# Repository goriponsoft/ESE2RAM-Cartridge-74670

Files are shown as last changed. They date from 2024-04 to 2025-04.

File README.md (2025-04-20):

# 似非²RAMカートリッジ(1Mbyte版)
[English README is here](README-en.md)

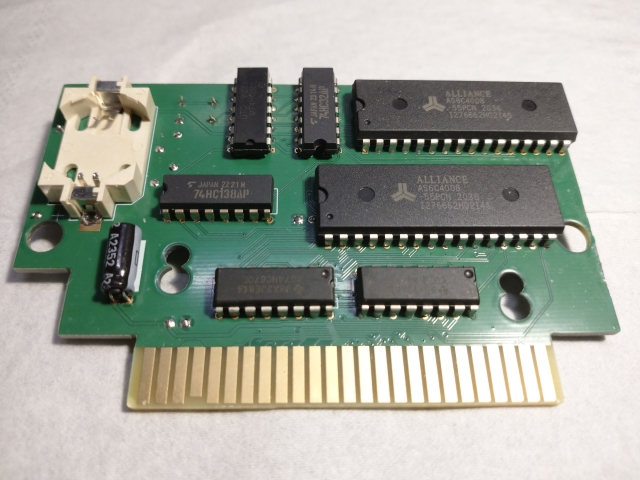
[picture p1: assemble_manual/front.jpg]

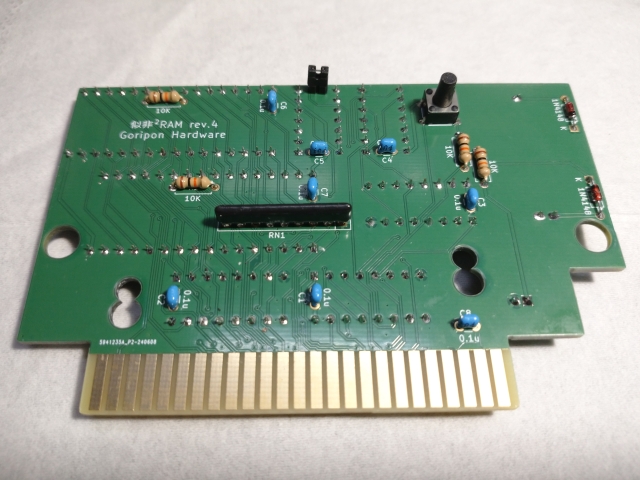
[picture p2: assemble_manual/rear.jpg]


これは、汎用ロジックICによりメガROMコントローラと同等の動作を実現し、それを利用して似非RAMを構築したMSX用カートリッジ(命名:似非・似非RAMまたは似非²RAM)です。
ごりぽんハードウェア(同人サークル・ごりぽんソフトウェアのハードウェア部門)により作成されました。

KiCAD7用の回路図データ・基板データ・ガーバーデータを、クリエイティブ・コモンズライセンス(CC-BY-NC)で公開しています。
[MGINST215.zip](https://github.com/goriponsoft/ESE2RAM-Cartridge-74670/blob/main/MGINST215.zip)および[KSAVER105.zip](https://github.com/goriponsoft/ESE2RAM-Cartridge-74670/blob/main/KSAVER105.zip)はCCライセンスの対象ではなく、元のライセンスと条件が適用されます。

X(旧Twitter): @goriponsoft

## 似非RAMディスク(似非RAM)とは？

[同人サークル・似非職人工房](http://www.hat.hi-ho.ne.jp/tujikawa/ese/)のつじかわ氏が考案した、ストレージなどとして使えるMSX用の汎用バックアップRAMカートリッジです。

通常は、ゲームのメガROMカートリッジを改造し、ROMをRAMに置き換えることで制作します。MGINSTコマンドによりDOSカーネルをインストールしてSSDのようなストレージとして利用したり(似非RAMディスク)、メガROMのイメージを読み込ませて動作させたりすることができます。

もともとストレージとしての使用を前提に考案されたため、カートリッジ自体も「似非RAMディスク」と呼ぶほうが一般的です。

なお、所有していないゲームのイメージを読み込ませて利用することは違法行為です。通常は似非RAMディスクの他、似非RAMに改造することで使用できなくなる改造元ゲームカートリッジのイメージ(改造前にファイルに書き出しておく必要あり)、フリーウェア、自作ROMゲーム、などを動作させるのに使用します。

似非RAMディスクについての詳細は、[似非職人工房の似非RAMディスクのページ](http://www.hat.hi-ho.ne.jp/tujikawa/ese/eseram.html)を参照してください。

## 似非²RAM(似非・似非RAM)とは？

近年MSXゲームの入手自体が難しくなり、貴重になってしまったメガROMカートリッジを潰して似非RAMにするのはかなり躊躇われる状況でした。そこで、普通に入手できる汎用ロジックICを使い、メガROMコントローラーと同等の回路を実現し、それを利用して似非RAMとして組み上げたのがこのカートリッジです。

似非RAMでありながら、メガROMコントローラを使用していない「似て非なる似非RAM」ということで「似非・似非RAM」、転じて「似非の2乗」で「似非²RAM」と命名しました。上付き文字の使用に問題がある場合は「似非2RAM」や「似非似非RAM」でも構いません。英語表記は「ESE-ESE-RAM」または「ESE2-RAM」です。

## 部品表
注意: 基板Rev.6以降U3～U5が74HCシリーズから74AHCシリーズに変更されています
|部品番号|内容|数量|
|:--|:--|--:|
|BT1|CR2032電池ホルダ "CH29-2032LF"/"CH28-2032LF(TR)"/"CH004-2032LF"/"CH004-2032LF"のいずれか|1|
|C1-C8|セラミックコンデンサ 0.1μF・50V・2.5mmピッチ|8|
|C9|電解コンデンサ 47μF・16V|1|
|D1-D2|ダイオード "1N4148"|2|
|IC1-IC2|4Mbit SRAM(628512タイプ・512K×8) DIP-32 "AS6C4008"など|2|
|R1-R4|抵抗 1/4W・10KΩ|4|
|RN1|集合抵抗 8素子・10KΩ SIP-9|1|
|S1|6×6mm タクトスイッチ "TVDP01-095BB1"|1|
|U1-U2|汎用ロジックIC "74HC670"|2|
|U3|汎用ロジックIC "74AHC138"|1|
|U4|汎用ロジックIC "74AHC00"|1|
|U5|汎用ロジックIC "74AHC32"|1|
|-|CR2032電池|1|

## 組み立て方
基板の実装面積の関係で、抵抗、コンデンサ、ダイオードなどの部品が裏面(ハンダ面)に配置されているため、組み立てには注意が必要です。

[詳細な組み立てマニュアル(日本語版)はこちら](assemble_manual/main.md)

1. 基板を裏返して(コネクタの傍に「Front」と書かれている側が表面です)、シルク印刷を参考に、ダイオード、抵抗、セラミックコンデンサ、集合抵抗、の順で部品を配置して表側(部品面)からハンダ付けします。ハンダを盛りすぎると、ICと基板の間に隙間ができるので、ハンダの量は控えめにしてハンダ付けしてください。
2. ハンダ付けしたら、表面に余ったリードを切断します。リードが余分に残っていると、やはりICと基板の間に隙間ができるので、こちらもできるだけ短くなるように切断してください。
3. 基板を表に戻し、IC、電解コンデンサ、セラミックコンデンサを配置し、通常通り裏面(ハンダ面)からハンダ付けしていきます。電解コンデンサはシルク印刷の方向に横倒しにして実装してください(縦に実装するとカートリッジシェルに収まりません)。ICやコンデンサのリードの処理は通常通りで構いません。
4. タクトスイッチと電池ホルダをハンダ付けします。標準では、タクトスイッチは裏面、電池ホルダは表面に配置しますが、逆の面に配置することもできますので、お好みで配置してください。
5. ショートや部品の付け間違いがないことを念入りに確認したうえで、MSX実機に挿して動作を確認します。似非RAMディスクとして使わない場合でも、動作確認にはMGINSTを使うのが簡単です。

## 準備 (似非RAMディスクとして使う場合)
1. 似非インストーラー(MGINST.COM)とカーネルセーバー(KSAVER.COM)を入手します([似非職人工房・非公認出張所(似非なページ)](http://www.big.or.jp/~saibara/msx/ese/index-j.html)よりLHA形式のアーカイブをダウンロードすることができます。また、ZIP形式にアーカイブしなおした[MGINST215.zip](https://github.com/goriponsoft/ESE2RAM-Cartridge-74670/blob/main/MGINST215.zip)と[KSAVER105.zip](https://github.com/goriponsoft/ESE2RAM-Cartridge-74670/blob/main/KSAVER105.zip)も、こちらで用意してあります。)
2. 何らかのMSXで起動可能なストレージ(通常はフロッピーディスク)に上記ツールを展開したものと、MSX-DOSのシステムファイル(MSXDOS.SYS/COMMAND.COM)をコピーします。MSX-DOS2カーネル利用の場合は、加えてMSX-DOS2のシステムファイル(MSXDOS2.SYS/COMMAND2.COM)をコピーしておくと、似非RAMインストール時に自動的にコピーされ、MSX-DOS2で起動することができるようになります。
3. MSX実機に似非²RAMカートリッジを挿し、タクトスイッチを押したまま電源を入れ、手順2で作成したストレージからMSX-DOS(またはMSX-DOS2)を起動します。
4. KSAVER.COMを使用し、MSX本体からMSX-DOSまたはMSX-DOS2のカーネルをファイルに保存します(詳細はKSAVERの付属ドキュメントを参照)。
5. MGINST.COMを使用し、手順4で保存したカーネルのファイルを指定して似非RAMカーネルをインストールします(詳細はMGINSTの付属ドキュメントを参照)。
6. リセットし似非RAMディスクから起動することを確認します。

手順4で保存したカーネルファイルは不要ですので、削除してしまっても構いません。残しておくと、似非RAMディスクの再インストール時に手順を省略できます。

手順5でエラーが出る場合は、部品のハンダ付け不良の可能性が高いので、基板をチェックしてみてください。

## 使い方 (メガROMソフトウェアを動かす場合)
使用した部品の機能の関係で、当カートリッジでは、セグメント番号の初期値がASCIIマッパーと異なっているため、プログラムによるレジスタの初期化が必須となっています。似非RAMディスクやゲームを含む、ほとんどのメガROMソフトウェアでは適切に初期化が行われているので問題ありませんが、初期化を怠っていたり、セグメント初期値が特定の値であることを期待しているソフトウェアは動作しない場合があります。

当カートリッジの起動直後もしくはリセット直後のバンクは以下のようになっています。

|バンクアドレス|レジスタアドレス|セグメント番号|
|:--|:--|--:|
|4000h-5FFFh|6000h-67FFh|0|
|6000h-7FFFh|6800h-6FFFh|0|
|8000h-9FFFh|7000h-77FFh|0|
|A000h-BFFFh|7800h-7FFFh|0|

この状態からレジスタに値を書き込むと、書き込んだレジスタは書き込んだ値に、書き込まれていないレジスタは不定値に切り替わります。

例えば6000hに0を書き込んだ場合は以下のようになります。

|バンクアドレス|セグメント番号|
|:--|--:|
|4000h-5FFFh|0|
|6000h-7FFFh|不定|
|8000h-9FFFh|不定|
|A000h-BFFFh|不定|

このため、当カートリッジで自作メガROMソフトウェアを動作させる場合は、INITエントリのできるだけ早い段階で、実行中のアドレスを含むバンクのレジスタに0を書き込んで初期化する必要があります。実行中のアドレスを含まないバンクのレジスタに先に書き込んでしまうと、実行中のプログラムが不定のバンクに切り替わり、ほとんどの場合は暴走します。また、書き込まれなかったレジスタの値は不定ですので、必要であれば初期化を行ってください。

通常はセグメント#0に以下のコードを配置し、ROMヘッダのINITエントリより4000h～5FFFhバンクのコードとして呼び出せば、問題なく初期化できます。
```
	xor		a
	ld		(6000h),a
	ld		(6800h),a
	ld		(7000h),a
	ld		(7800h),a
```

## 互換性情報
動作確認済のハードウェア(順不同)について

ご報告いただいたものは順次追加していきます

### 動作不良が確認されている機種と症状

- ビクター HC-90 および HC-95 (MSX2) : RAMから読み出されたデータが壊れるため正常動作しない
- 東芝 HX-E601 (拡張スロット) : 認識されず起動しない

### 正常動作が確認されている機種

- パナソニック FS-A1ST
- ソニー HB-F1XV
- 三菱 ML-G30model1 および ML-G30model2
- ヤマハ YIS503 および CX5F
- ヤマハ YIS604/128 および CX7M/128
- 三洋 WAVY70FD および WAVY70FD2
- 東芝 HX-31
- 三菱 ML-8000
- ゼネラル PCT-50 および PCT-55
- ソニー HB-F500

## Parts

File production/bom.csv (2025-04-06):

Designator | Footprint | Quantity | Value | LCSC Part #
BT1 | BatteryHolder_CH2x-2032LF | 1 | CR2032
C1, C2, C3, C4, C5, C6, C7, C8 | C_Disc_D3.0mm_W1.6mm_P2.50mm | 8 | 0.1u
C9 | CP_Radial_D5.0mm_P2.00mm_Horizontal | 1 | 47u
D1, D2 | D_DO-35_SOD27_P7.62mm_Horizontal | 2 | 1N4148
IC1, IC2 | DIP32_600mil_FineLongPad | 2 | 4M SRAM
R1, R2, R3, R4 | R_Axial_DIN0207_L6.3mm_D2.5mm_P7.62mm_Horizontal | 4 | 10K
RN1 | R_Array_SIP9 | 1 | 10k
S1 | DTS63NV | 1 | DTS-63N-V
U1, U2 | DIP16_300mil_FineLongPad | 2 | 74HC670
U3 | DIP16_300mil_FineLongPad | 1 | 74AHC138
U4 | DIP14_300mil_FineLongPad | 1 | 74AHC00
U5 | DIP14_300mil_FineLongPad | 1 | 74AHC32

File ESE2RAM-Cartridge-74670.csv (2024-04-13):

Source: | Y:\Project\ESE2RAM-Cartridge-74670\ESE2RAM-Cartridge-74670.kicad_sch
Date: | 2024/04/13 19:58:52
Tool: | Eeschema 7.0.8
Generator: | C:\Program Files\KiCad\7.0\bin\scripting\plugins/bom_csv_grouped_by_value_with_fp.py
Component Count: | 25
Ref | Qnty | Value | Cmp name | Footprint | Description | Vendor | DNP
BT1 | 1 | CR2032 | Battery_Cell | ProjectLibrary:BatteryHolder_CH2x-2032LF | Single-cell battery
C1, C2, C3, C4, C5, C6, C7, C8 | 8 | 0.1u | C_Small | Capacitor_THT:C_Disc_D3.0mm_W1.6mm_P2.50mm | Unpolarized capacitor, small symbol
C9 | 1 | 47u | C_Polarized_Small | ProjectLibrary:CP_Radial_D5.0mm_P2.00mm_Horizontal | Polarized capacitor, small symbol
D1, D2 | 2 | 1N4148 | 1N4148 | Diode_THT:D_DO-35_SOD27_P7.62mm_Horizontal | 100V 0.15A standard switching diode, DO-35
IC1, IC2 | 2 | 4M SRAM | AS6C4008-55PIN | ProjectLibrary:DIP32_600mil_FineLongPad | SRAM 4M, 2.7-5.5V, 55ns 512K x 8 Asynch SRAM
R1, R2, R3, R4 | 4 | 10K | R_Small | Resistor_THT:R_Axial_DIN0207_L6.3mm_D2.5mm_P7.62mm_Horizontal | Resistor, small symbol
RN1 | 1 | 10k | R_Network08 | Resistor_THT:R_Array_SIP9 | 8 resistor network, star topology, bussed resistors, small symbol
S1 | 1 | DTS-63N-V | DTS-63N-V | ProjectLibrary:DTS63NV | 6x6 Through Hole & Ground Terminal Type,TS 6MM V H=7.0 160gf BULK
U1, U2 | 2 | 74HC670 | 74LS670 | ProjectLibrary:DIP16_300mil_FineLongPad | 4 x 4 Register Files 3-State Outputs
U3 | 1 | 74HC138 | 74LS138 | ProjectLibrary:DIP16_300mil_FineLongPad | Decoder 3 to 8 active low outputs
U4 | 1 | 74HC00 | 74LS00 | ProjectLibrary:DIP14_300mil_FineLongPad | quad 2-input NAND gate
U5 | 1 | 74HC32 | 74HC32 | ProjectLibrary:DIP14_300mil_FineLongPad | Quad 2-input OR

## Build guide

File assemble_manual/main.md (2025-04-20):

# 似非²RAM組み立てマニュアル

## 0. 組み立てを始める前に

実は本キットには、いくつかの改造ポイントがあるのですが、組み立て手順の関係で、組み立て開始前に改造のための加工をしておかないと、後からでは改造出来なくなってしまうものがあります。
ということで、いきなりですが改造ポイントについての説明です。改造する気が無い方は、読み飛ばしていただいて構いません。

以下、基板のコネクタ部分を手前(下)に見た位置で示します。基板の表裏については、基板右下コネクタ付近に「Front」の白いシルク印刷のある側が「表」側、基板左上に「似非²RAM」のシルク印刷の文字がある側が「裏」側です。

### ① 1024KB/512KB切替ジャンパピン

U5(74HC32)の7ピンと8ピンの間、基板の上端ギリギリのところに、パスコンとは別の横並びのパターンがあります。これがRAM容量切替ジャンパのパターンです。

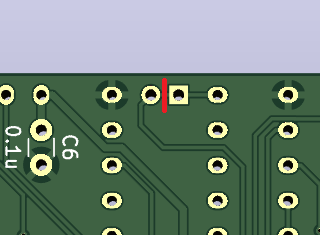
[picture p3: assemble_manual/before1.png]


通常は容量は1MB(1024KB)固定となりますが、基板の裏側の2つのパターンの間の配線(図の赤線)をカットし、同じく裏側からキット付属の2mmピンヘッダ(ジャンパーピン付)を差し込み、表側からハンダ付けすることで、ジャンパピンを挿した状態で1024KB、抜いた状態で512KB、2つの容量に切り替えることができるようになります。512KB時のバンク割当は、0～63(128～191)にIC1のSRAMが見え、64～127(192～255)には何も(バンクのゴーストも)見えない、という状態になります。

こちらの改造ポイントは、表側に74HC32が被せられハンダ付けされてしまうので、ICより先に処理しておかないと、ハンダ付けするパターンがICの下に隠れてしまい、ジャンパピンを取り付けることができなくなってしまいます。また、カットする面にはジャンパピンが配置されているため、パターンカットする前にジャンパピンを付けてしまうと機能しません。

主にメガROMソフトの開発者向けの機能であり、似非RAMディスクとしてのみ使用するのであれば、改造の必要はありません。(なお完成品では改造済みの状態になっています)

### ② RAM減量(512KB化)

①は「1024Kと512Kを切り替えるジャンパ」の改造でしたが、こちらは「容量自体を512KBに減量する」改造です。当然ながらこちらの改造を行った場合、①のジャンパは意味が無くなります。

IC2のSRAMを実装しないことで容量を512KBにすることができます。またIC2に関連するC7とR2も外すことができます。バンク割当は①の512KB時と同様です。

単に部品を省略するだけなので、こちらの改造ポイントは、特に順序などに制限はありません。

### ③ ライトプロテクトスイッチ

通常はSRAMへは常時書き込み許可ですが、U2(74HC670)の6番ピンの裏面側から上方向に伸びている細いパターンをカットし(図の赤線・該当箇所の上部のみ基板の色が少し違います)、この6番ピンとU4(74HC00)の10番ピンの間にスイッチ(キットには付属していません)を付けることで、OFFで書き込み禁止、ONで書き込み許可となる、ライトプロテクトスイッチを付けることができます。

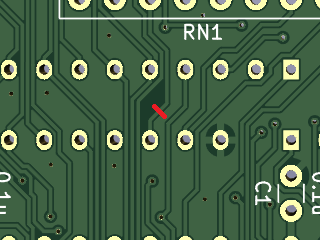
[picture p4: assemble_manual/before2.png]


なお、こちらの改造ポイントは、パターンに重なる部品などは無いため、後からでも加工が可能です。

ただし、このライトプロテクトスイッチは、ソフトウェアからの書き込みに対しては有効ですが、ハードウェアが原因であるSRAM内容の消失に対しては無力です。書き込み禁止にしていたとしても、内容が消失する可能性はありますので、過度の期待はしないでください。

## 1. 裏面からの部品の取り付け(1)

本キットでは基板の面積の都合で、表面と裏面で重なる位置に部品が配置されているため、基板両面から部品の取り付けが必要です。ここでは、裏面(本来はハンダ面)からの取り付けが必要な部品について、取り付け手順を説明します。



### ① 抵抗の取り付け

抵抗のリードを抵抗の本体ギリギリのところで折り曲げ(キットの1/4W抵抗であれば丁度良い幅になるよう設計されています)、R1～R4のパターンに差し込み、テープなどで仮止めしてから、裏返して表面からハンダ付けします。抵抗は全て同じ抵抗値で、向きもありませんので、どれをどの向きに差し込んでも大丈夫です。

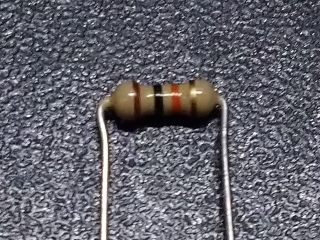
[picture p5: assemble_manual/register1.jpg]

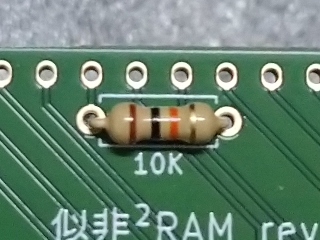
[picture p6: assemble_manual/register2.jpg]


表面の部品と重なる部分については、ハンダを少なめにして、できるだけ盛り上がりのないようにハンダ付けし、余分なリードは基板面ギリギリのところでカットします。

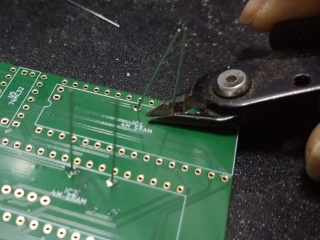
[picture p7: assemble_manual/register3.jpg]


基板に抵抗を取り付けた状態です。

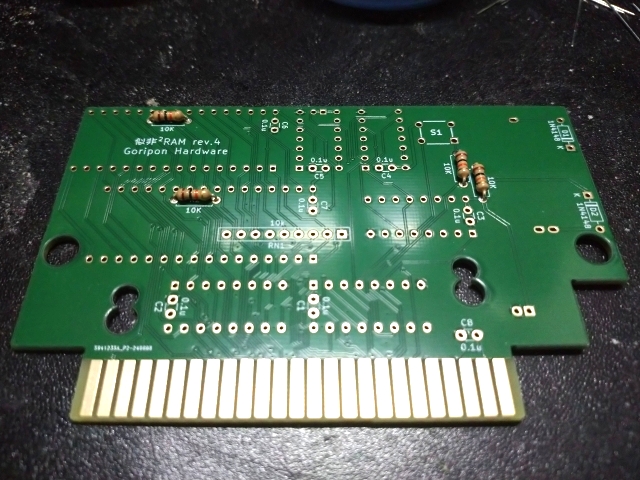
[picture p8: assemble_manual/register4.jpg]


### ② ダイオードの取り付け

ダイオードのリードを折り曲げ(前項目の抵抗と同じくらいの幅になるようにします)、D1～D2のパターンに差し込み、テープなどで仮止めしてから、裏返して表面からハンダ付けします。ダイオードは青いラインの入っている側がK(カソード)ですので、基板上の白いシルク印刷の「K」と合わせて、向きを間違えないように差し込んでください。

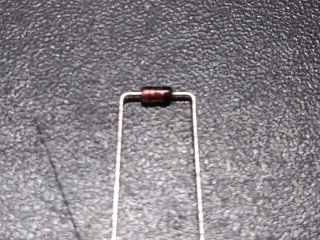
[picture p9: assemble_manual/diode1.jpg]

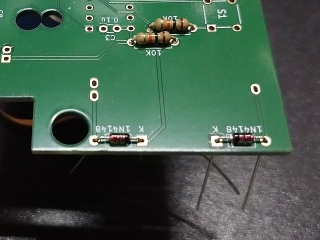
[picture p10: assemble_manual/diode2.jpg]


ダイオードは裏面に重なる部品が無いため、ハンダ付けは通常通りで構いません。ただし、あまりリードが長すぎるとボタン電池と干渉する可能性があります。

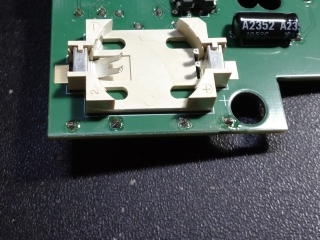
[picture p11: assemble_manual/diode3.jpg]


基板にダイオードを取り付けた状態です。

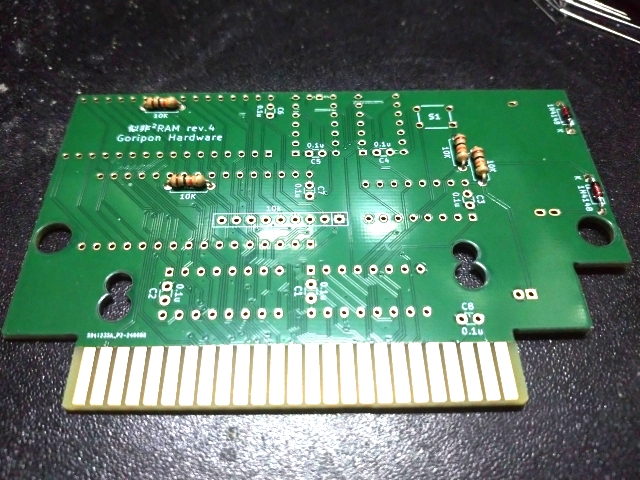
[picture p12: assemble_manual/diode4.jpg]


### ③ セラミックコンデンサの取り付け

セラミックコンデンサ(キットでは積層セラミックコンデンサ)は加工の必要はありません。リードの曲がりを直してそのまま差し込めばスポッと嵌ります。C1～C8のパターンに差し込み、テープなどで仮止めしてから、裏返して表面からハンダ付けします。

<!-- 要撮影：黒バック・セラミックコンデンサ差し込み -->
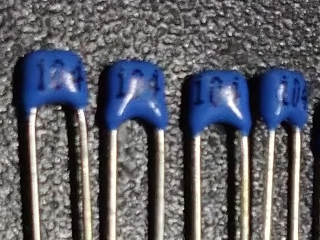
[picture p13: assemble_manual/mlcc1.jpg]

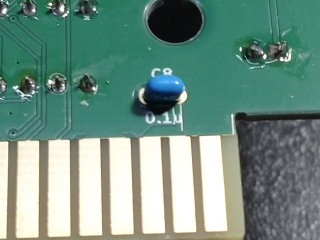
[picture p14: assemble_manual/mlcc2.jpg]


表面の部品と重なる部分については、抵抗と同様にハンダを少なめにして、できるだけ盛り上がりのないようにハンダ付けし、余分なリードは基板面ギリギリのところでカットします。

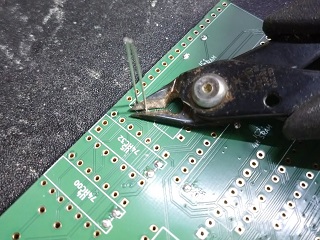
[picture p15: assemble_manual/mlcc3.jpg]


基板にセラミックコンデンサを取り付けた状態です。

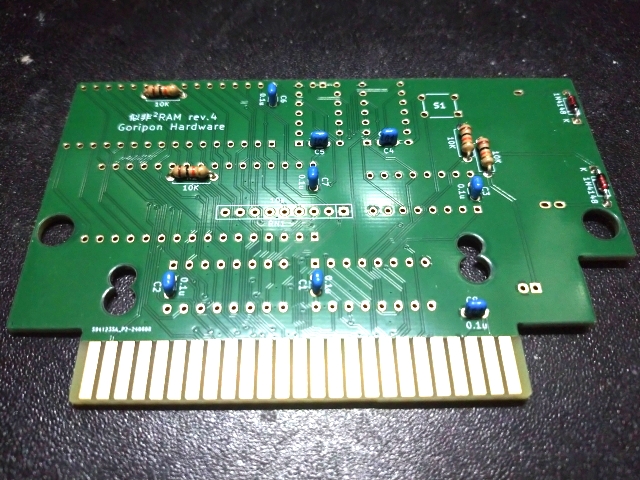
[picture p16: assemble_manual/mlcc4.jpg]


### ④ 集合抵抗の取り付け

集合抵抗は加工の必要はありません。集合抵抗の方向を間違えないようRN1のパターンに差し込み、テープなどで仮止めしてから、裏返して表面からハンダ付けします。集合抵抗の表面に印が印刷されている側が1番ピンになりますので、基板の白いシルク印刷で正方形に囲われた1番ピン側に合わせて、向きを間違えないように差し込んでください。

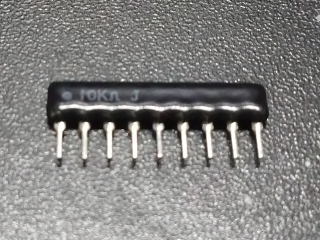
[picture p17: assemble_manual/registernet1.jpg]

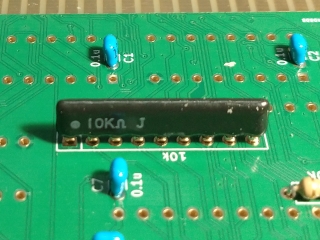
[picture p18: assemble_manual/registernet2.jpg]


表面の部品と重なる部分については、抵抗と同様にハンダを少なめにして、できるだけ盛り上がりのないようにハンダ付けし、余分なリードは基板面ギリギリのところでカットします。

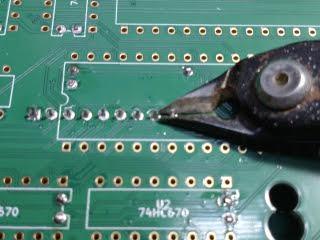
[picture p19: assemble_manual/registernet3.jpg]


基板に集合抵抗を取り付けた状態です。

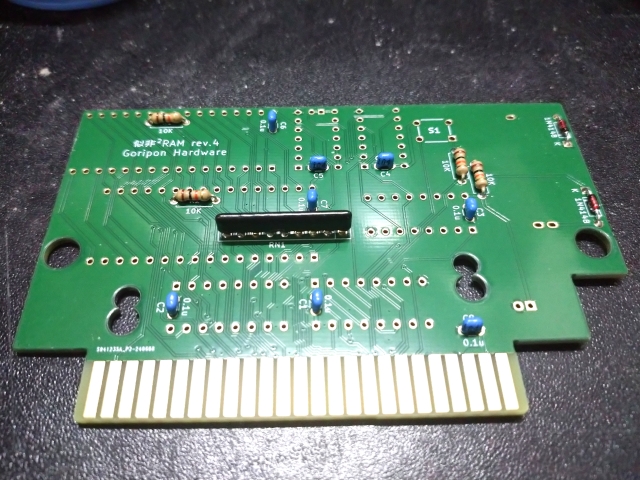
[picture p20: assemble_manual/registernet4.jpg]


### ⑤ 1024KB/512KB切替ジャンパピンの取り付け

改造しない場合はこの項目は読み飛ばしていただいて構いません。

改造する場合は、ここで1024KB/512KB切替ジャンパピンのパターンをカットし(カット後にテスタなどで確実にカットされていることとGNDや+5Vとショートしていないことを確認しておくと安心です)、付属の2mmピッチピンヘッダ(ジャンパピン付)をパターンに差し込み、テープなどで仮止めしてから、裏返して表面からハンダ付けします。

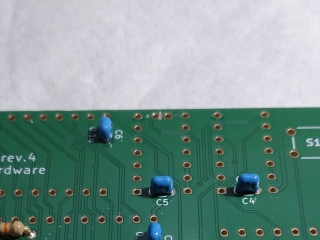
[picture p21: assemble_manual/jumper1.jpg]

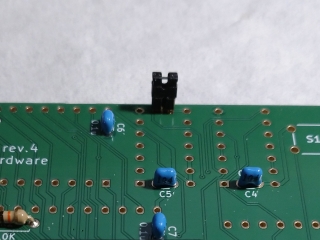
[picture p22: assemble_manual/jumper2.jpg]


基板にジャンパピンを取り付けた状態です。

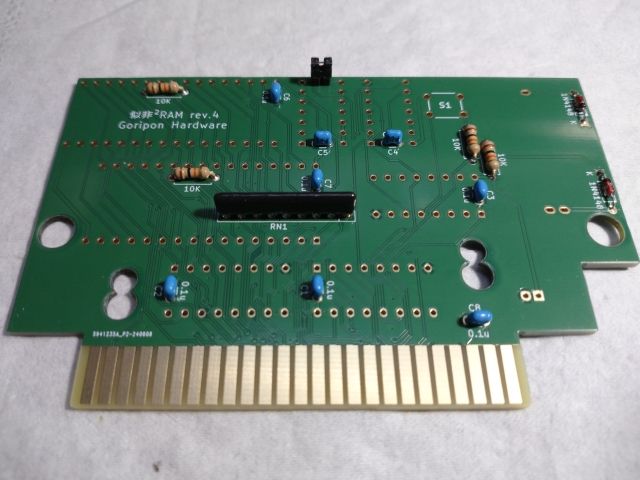
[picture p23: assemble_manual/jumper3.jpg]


### ⑥ 裏面取付部品の確認

基板を裏面から見て、部品の付け忘れがないか、表面から見て、ハンダし忘れがないか、ハンダ部分やリードが必要以上に盛り上がったり残ったりしていないか、などを確認します。特に表面にICが重なる部品のミスは、ICを取り付けてしまった後では取り返しがつかないので、付け忘れとハンダし忘れは特に注意して確認してください。

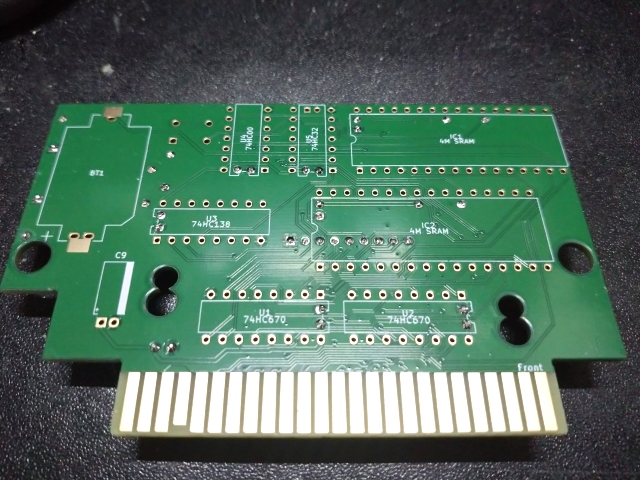
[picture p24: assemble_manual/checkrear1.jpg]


なお、他の部品のハンダ付けの邪魔になるため、この時点ではタクトスイッチはハンダ付けしません。もし間違えて先にハンダ付けしてしまった場合でも、(取り付ける面を間違えていなければ)若干取り回しが悪くなるだけで特に問題はありませんので、そのまま進めてください。

## 2. 表面からの部品の取り付け

裏面の部品の取り付けが終わりましたので、引き続き通常通り、表面に部品を取り付けます。

### ① ICの取り付け

基板上のシルク印刷の印を見ながら、ICの向きを間違えないようU1～U5およびIC1～IC2のパターンに差し込み、テープなどで仮止めしてから、裏返して裏面からハンダ付けします。U1～U2はマークが右、U4～U5はマークが下、U3とIC1～IC2はマークが左、になっていますので注意してください。

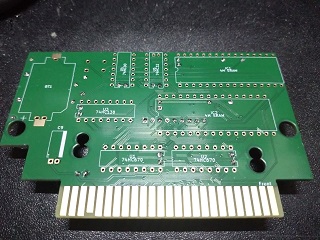
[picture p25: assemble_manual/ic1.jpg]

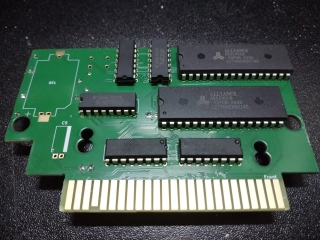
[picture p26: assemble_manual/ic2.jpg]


すでに裏面には抵抗・コンデンサ・ダイオードが取り受けられており、ハンダゴテをあてる際にも邪魔になることがありますので、適宜、基板の向きを変えてコテ先を当てやすい向きにして作業するようにしてください。

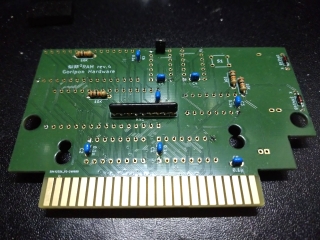
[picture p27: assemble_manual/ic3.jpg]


### ② ボタン電池ホルダの取り付け

ボタン電池ホルダの向きを間違えないようBT1のパターンに差し込み、テープなどで仮止めしてから、裏返して表面からハンダ付けします。コネクタ側がプラスになりますので、向きを間違えないように取り付けてください。

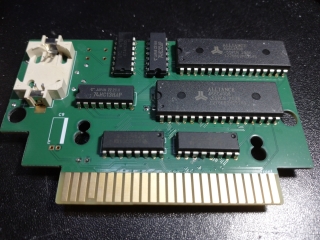
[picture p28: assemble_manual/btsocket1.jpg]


### ② 電解コンデンサの取り付け

電解コンデンサのリードをコンデンサの本体ギリギリのところで90°折り曲げ、C9のパターンに基板と並行になるように差し込み、テープなどで仮止めしてから、裏返して表面からハンダ付けします。電解コンデンサはマイナス側に印がついていますので、基板のシルク印刷で白い帯が描かれている側に合わせて、向きを間違えないように曲げて差し込んでください。

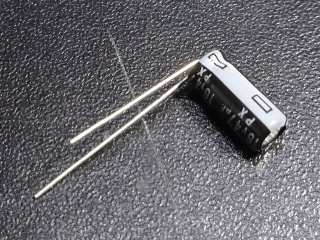
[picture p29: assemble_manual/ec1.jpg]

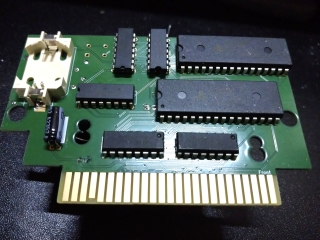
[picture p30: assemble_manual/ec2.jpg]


### ③ 表面取付部品の確認

基板を表面から見て、部品の付け忘れがないか、裏面から見て、ハンダし忘れがないか、などを確認します。

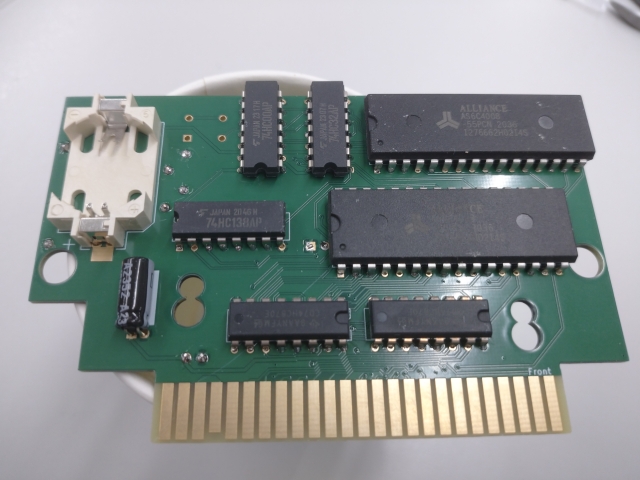
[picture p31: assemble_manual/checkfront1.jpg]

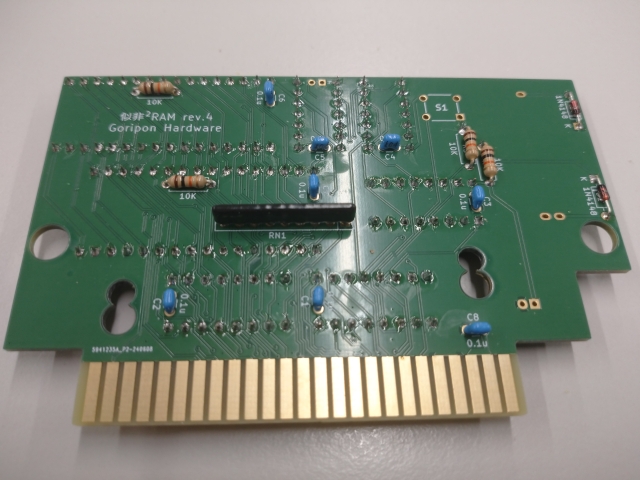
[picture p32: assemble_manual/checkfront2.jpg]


## 3. 裏面からの部品の取り付け(2)

最後にもう一度、基板を裏返して部品を取り付けます。

### ① タクトスイッチの取り付け

タクトスイッチは加工の必要はありません。タクトスイッチをS1ののパターンに差し込み(差し込むだけで固定されます)、裏返して表面からハンダ付けします。タクトスイッチは向きが間違っていると差し込めません(差し込めれば向きは関係ありません)。

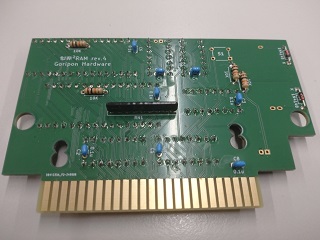
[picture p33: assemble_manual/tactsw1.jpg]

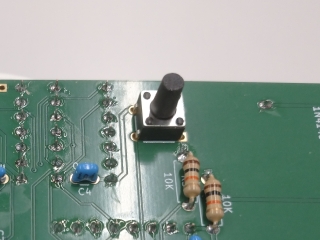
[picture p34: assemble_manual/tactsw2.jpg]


## 4. 全取り付け部品の最終確認

組み立ての最後に、すべての部品が正しく取り付けられているかどうかを確認します。

表面から見て、電解コンデンサ・ボタン電池ホルダ・各種ICが、向きも含め正しく取り付けられているかどうか、裏面の部品のハンダ付けが(この時点ではほとんど見えないと思いますが…)正しく行われているかどうか、を確認してください。



裏面から見て、抵抗・ダイオード・セラミックコンデンサ・集合抵抗・タクトスイッチ(改造した場合はジャンパピンも)が、向きも含め正しく取り付けられているかどうか、表面の部品のはんだ付けが正しく行われているかどうか、を確認してください。



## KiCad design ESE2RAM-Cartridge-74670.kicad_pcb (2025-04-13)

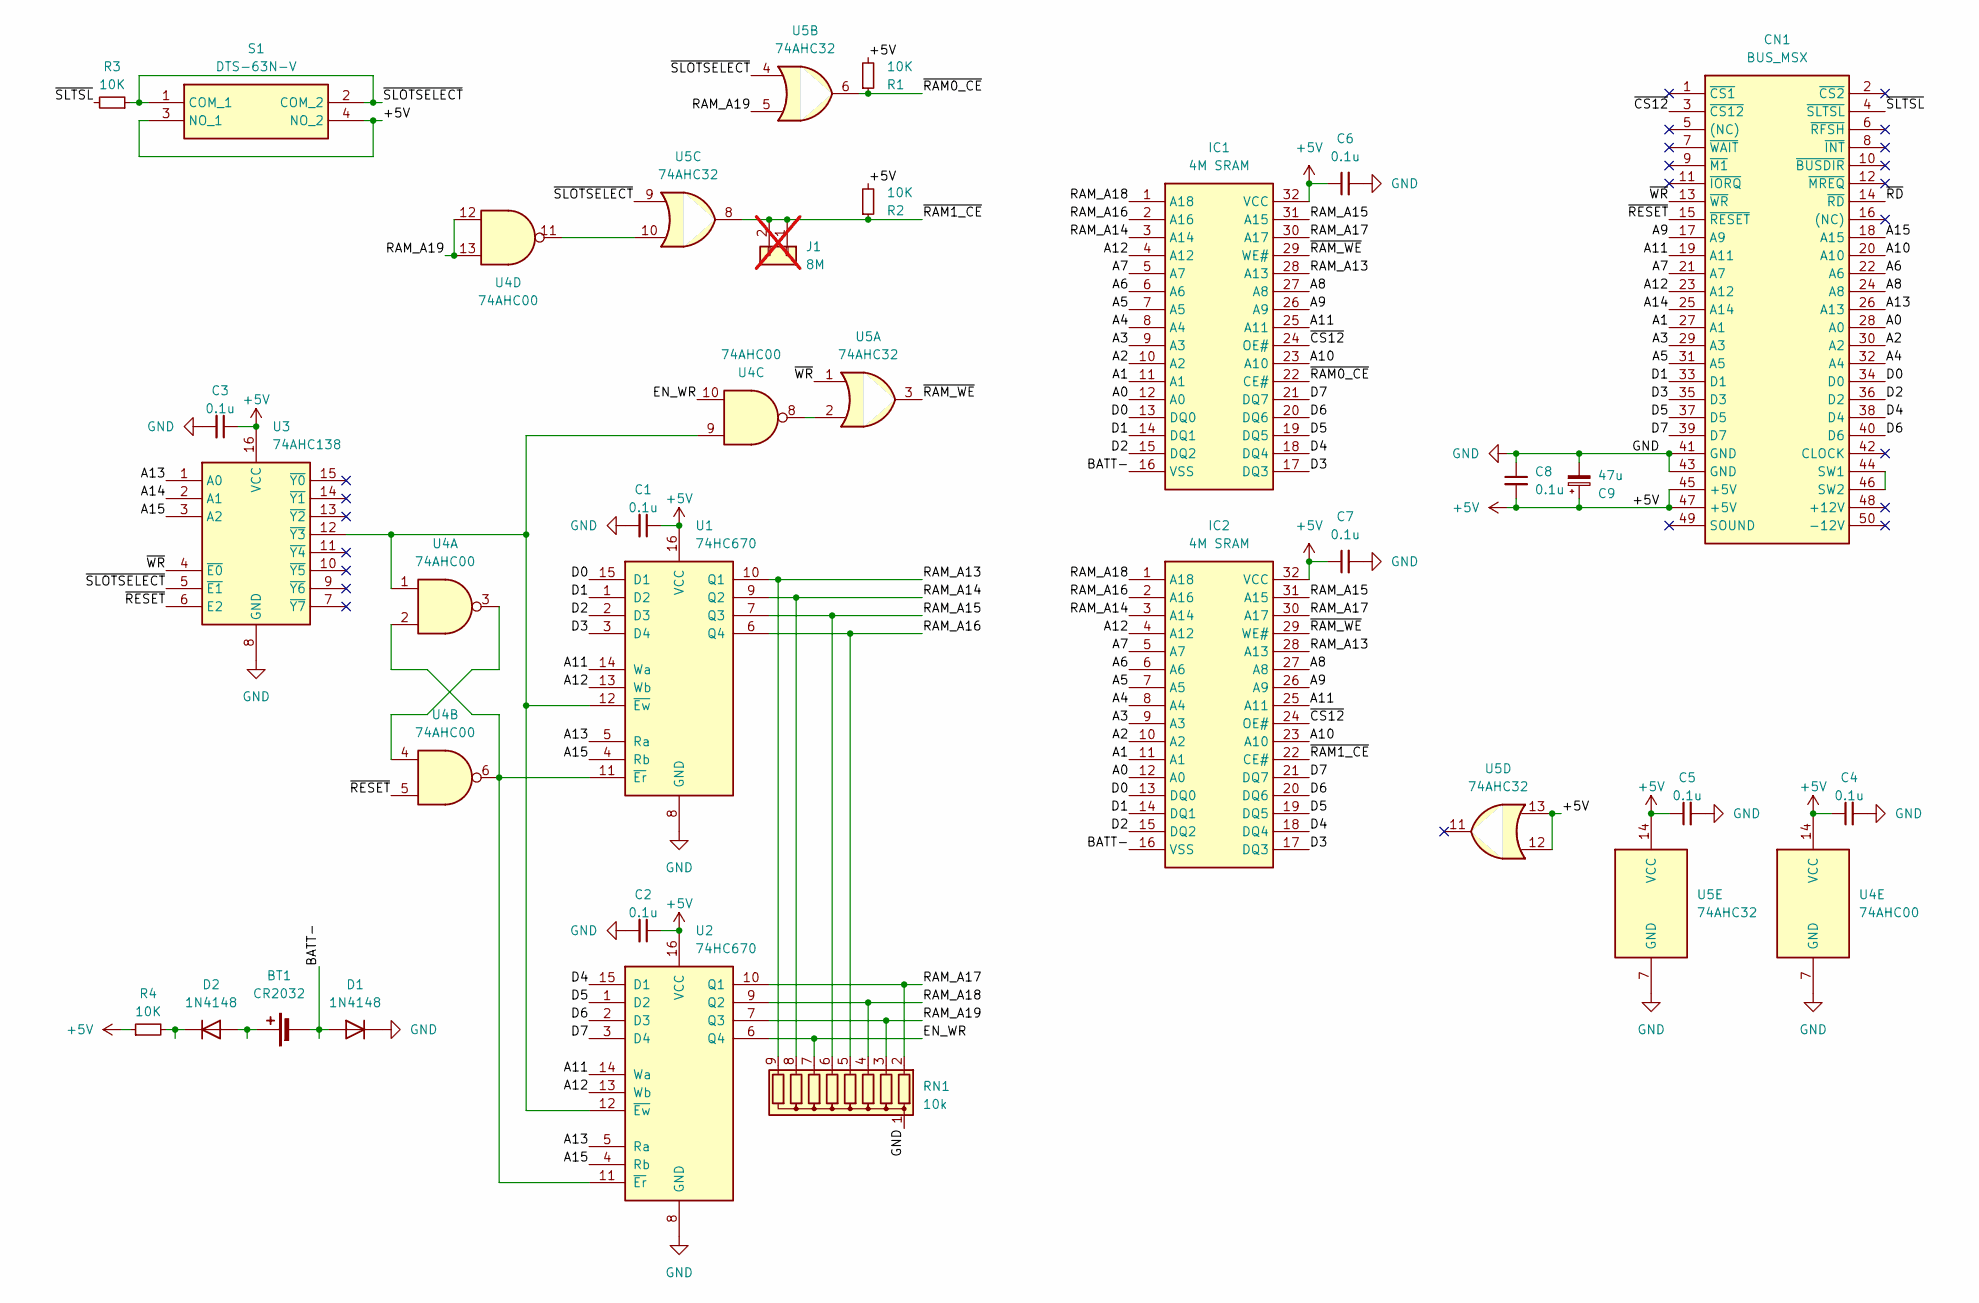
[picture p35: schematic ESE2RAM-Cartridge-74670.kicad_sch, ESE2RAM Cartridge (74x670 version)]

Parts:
BT1: CR2032; BatteryHolder_CH2x-2032LF
C1, C2, C3, C4, C5, C6, C7, C8: 0.1u; C_Disc_D3.0mm_W1.6mm_P2.50mm
C9: 47u; CP_Radial_D5.0mm_P2.00mm_Horizontal
CN1: BUS_MSX; BUS_MSX_CARD_SHORT
D1, D2: 1N4148; D_DO-35_SOD27_P7.62mm_Horizontal
IC1, IC2: 4M SRAM; DIP32_600mil_FineLongPad; Manufacturer_Part_Number AS6C4008-55PIN; Mouser Part Number 913-AS6C4008-55PIN
J1: 8M; PinHeader_1x02_P2.00mm_Vertical; not fitted
R1, R2, R3, R4: 10K; R_Axial_DIN0207_L6.3mm_D2.5mm_P7.62mm_Horizontal
RN1: 10k; R_Array_SIP9
S1: DTS-63N-V; DTS63NV; Manufacturer_Part_Number DTS-63N-V; Mouser Part Number 113-DTS-63N-V
U1, U2: 74HC670; DIP16_300mil_FineLongPad
U3: 74AHC138; DIP16_300mil_FineLongPad
U4: 74AHC00; DIP14_300mil_FineLongPad
U5: 74AHC32; DIP14_300mil_FineLongPad

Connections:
+5V: C1.1, C2.1, C3.1, C4.1, C5.1, C6.1, C7.1, C8.2, C9.1, CN1.45 (+5V), CN1.47 (+5V), IC1.32 (VCC), IC2.32 (VCC), R1.2, R2.2, R4.1, S1.3 (NO_1), S1.4 (NO_2), U1.16 (VCC), U2.16 (VCC), U3.16 (VCC), U4.14 (VCC), U5.12, U5.13, U5.14 (VCC)
/A0: CN1.28 (A0), IC1.12 (A0), IC2.12 (A0)
/A1: CN1.27 (A1), IC1.11 (A1), IC2.11 (A1)
/A2: CN1.30 (A2), IC1.10 (A2), IC2.10 (A2)
/A3: CN1.29 (A3), IC1.9 (A3), IC2.9 (A3)
/A4: CN1.32 (A4), IC1.8 (A4), IC2.8 (A4)
/A5: CN1.31 (A5), IC1.7 (A5), IC2.7 (A5)
/A6: CN1.22 (A6), IC1.6 (A6), IC2.6 (A6)
/A7: CN1.21 (A7), IC1.5 (A7), IC2.5 (A7)
/A8: CN1.24 (A8), IC1.27 (A8), IC2.27 (A8)
/A9: CN1.17 (A9), IC1.26 (A9), IC2.26 (A9)
/A10: CN1.20 (A10), IC1.23 (A10), IC2.23 (A10)
/A11: CN1.19 (A11), IC1.25 (A11), IC2.25 (A11), U1.14 (Wa), U2.14 (Wa)
/A12: CN1.23 (A12), IC1.4 (A12), IC2.4 (A12), U1.13 (Wb), U2.13 (Wb)
/A13: CN1.26 (A13), U1.5 (Ra), U2.5 (Ra), U3.1 (A0)
/A14: CN1.25 (A14), U3.2 (A1)
/A15: CN1.18 (A15), U1.4 (Rb), U2.4 (Rb), U3.3 (A2)
/BATT-: BT1.2 (-), D1.2 (A), IC1.16 (VSS), IC2.16 (VSS)
/D0: CN1.34 (D0), IC1.13 (DQ0), IC2.13 (DQ0), U1.15 (D1)
/D1: CN1.33 (D1), IC1.14 (DQ1), IC2.14 (DQ1), U1.1 (D2)
/D2: CN1.36 (D2), IC1.15 (DQ2), IC2.15 (DQ2), U1.2 (D3)
/D3: CN1.35 (D3), IC1.17 (DQ3), IC2.17 (DQ3), U1.3 (D4)
/D4: CN1.38 (D4), IC1.18 (DQ4), IC2.18 (DQ4), U2.15 (D1)
/D5: CN1.37 (D5), IC1.19 (DQ5), IC2.19 (DQ5), U2.1 (D2)
/D6: CN1.40 (D6), IC1.20 (DQ6), IC2.20 (DQ6), U2.2 (D3)
/D7: CN1.39 (D7), IC1.21 (DQ7), IC2.21 (DQ7), U2.3 (D4)
/EN_WR: RN1.7 (R6), U2.6 (Q4), U4.10
/RAM_A13: IC1.28 (A13), IC2.28 (A13), RN1.9 (R8), U1.10 (Q1)
/RAM_A14: IC1.3 (A14), IC2.3 (A14), RN1.8 (R7), U1.9 (Q2)
/RAM_A15: IC1.31 (A15), IC2.31 (A15), RN1.6 (R5), U1.7 (Q3)
/RAM_A16: IC1.2 (A16), IC2.2 (A16), RN1.5 (R4), U1.6 (Q4)
/RAM_A17: IC1.30 (A17), IC2.30 (A17), RN1.2 (R1), U2.10 (Q1)
/RAM_A18: IC1.1 (A18), IC2.1 (A18), RN1.4 (R3), U2.9 (Q2)
/RAM_A19: RN1.3 (R2), U2.7 (Q3), U4.12, U4.13, U5.5
/~CS12: CN1.3 (~CS12), IC1.24 (OE#), IC2.24 (OE#)
/~RAM0_CE: IC1.22 (CE#), R1.1, U5.6
/~RAM1_CE: IC2.22 (CE#), J1.1, J1.2, R2.1, U5.8
/~RAM_WE: IC1.29 (WE#), IC2.29 (WE#), U5.3
/~RD: CN1.14 (~RD)
/~RESET: CN1.15 (~RESET), U3.6 (E2), U4.5
/~SLOTSELECT: R3.1, S1.1 (COM_1), S1.2 (COM_2), U3.5 (~E1), U5.4, U5.9
/~SLTSL: CN1.4 (~SLTSL), R3.2
/~WR: CN1.13 (~WR), U3.4 (~E0), U5.1
GND: C1.2, C2.2, C3.2, C4.2, C5.2, C6.2, C7.2, C8.1, C9.2, CN1.41 (GND), CN1.43 (GND), D1.1 (K), RN1.1 (common), U1.8 (GND), U2.8 (GND), U3.8 (GND), U4.7 (GND), U5.7 (GND)
unnamed: BT1.1 (+), D2.2 (A)
unnamed: CN1.44 (SW1), CN1.46 (SW2)
unnamed: D2.1 (K), R4.2
unnamed: U1.11 (~Er), U2.11 (~Er), U4.2, U4.6
unnamed: U1.12 (~Ew), U2.12 (~Ew), U3.12 (~Y3), U4.1, U4.9
unnamed: U4.3, U4.4
unnamed: U4.8, U5.2
unnamed: U4.11, U5.10

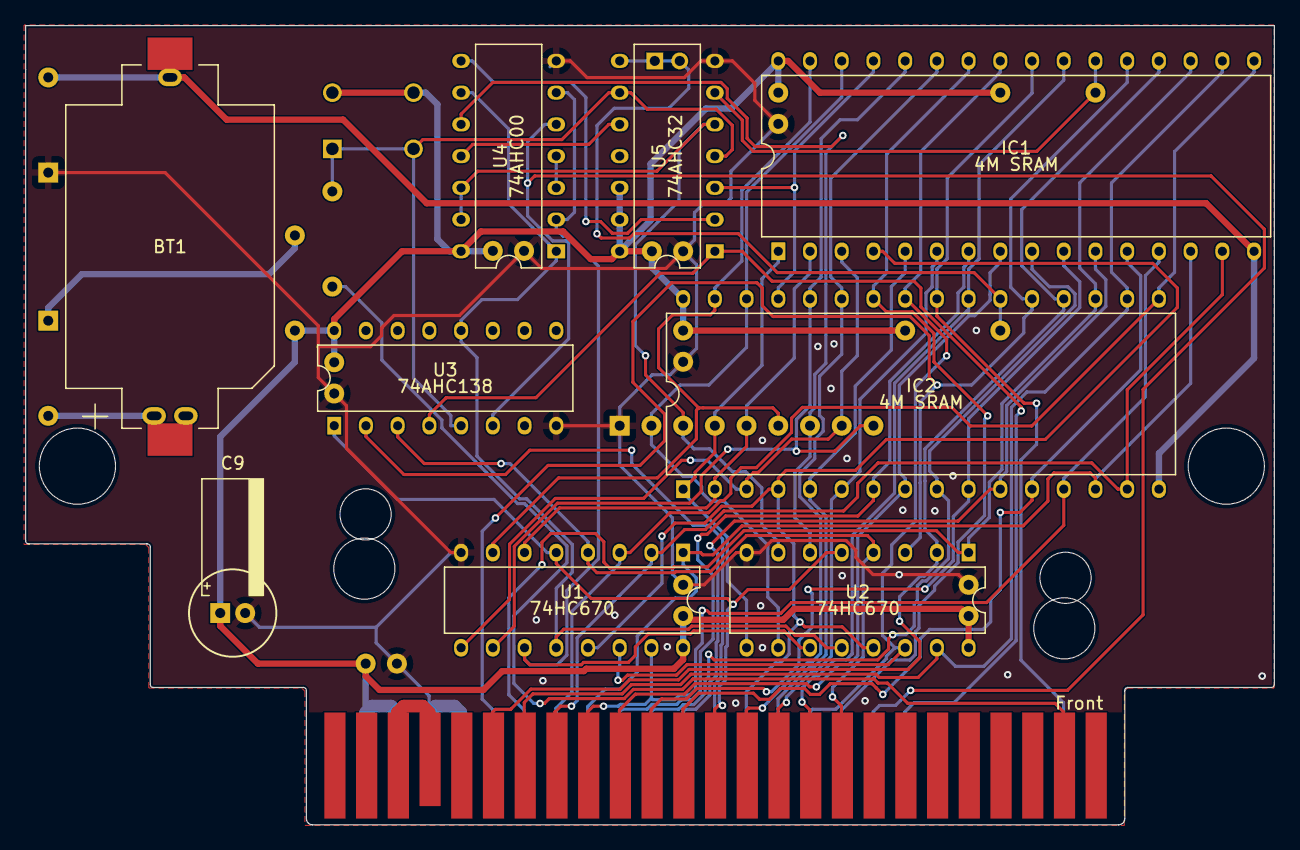
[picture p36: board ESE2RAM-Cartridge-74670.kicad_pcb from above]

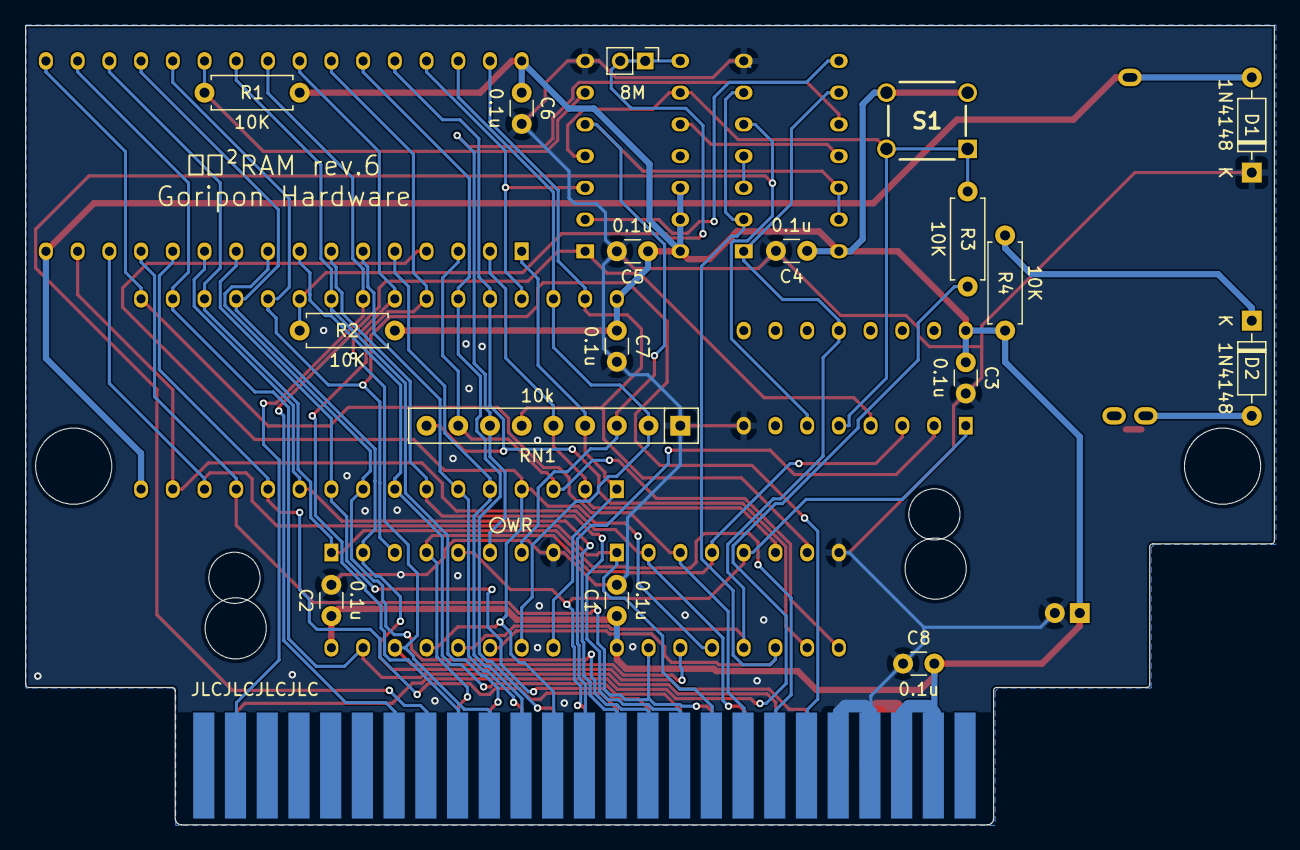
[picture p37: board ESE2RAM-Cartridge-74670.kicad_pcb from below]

Board: 2 copper layers, 100.0 x 64.0 mm, 27 parts (17 on the bottom side), 51 nets.

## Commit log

2024-03-24 First Release
    [ESE2RAM-Cartridge-74670.csv, ESE2RAM-Cartridge-74670.kicad_pcb, ESE2RAM-Cartridge-74670.kicad_sch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]
2024-03-25 Modified README
    Modified README
    Added "How to assemble" item.
2024-03-25 Modified schematic
    Modified schematic
    Change tactile switch.
    [ESE2RAM-Cartridge-74670.kicad_sch]
2024-03-25 Modified Schematic
    Modified Schematic
    Fixed DRC error in PCB data & Rebuilt Gerber data.
    [ESE2RAM-Cartridge-74670.kicad_pcb]
2024-03-27 Modified README
    公開しているデータについての説明を追加。
    Added explanation about published data.
2024-03-28 Modified README
    部品表のセラミックコンデンサにリード間隔を追加、組み立て方に動作確認の手順を追加、ほか細かい文言の修正。
    Added lead spacing to ceramic capacitors in the parts list, added operation confirmation steps to assembly instructions, and other minor wording corrections.
2024-03-31 Added tools archive.
    ツール類のzipアーカイブを追加。
    Added tool zip archive.
2024-03-31 Modified README
    KSAVER105.zipのライセンスに関する項目が抜けていたので追加。
    Added the item related to the license of KSAVER105.zip because it was missing.
2024-04-04 Modify Schematic
    プロジェクトローカルライブラリの設定が抜けていたのを修正。
    Fixed missing project local library settings.
    その他の細かな修正。
    Other minor corrections.
    [ESE2RAM-Cartridge-74670.csv, ESE2RAM-Cartridge-74670.kicad_pcb, ESE2RAM-Cartridge-74670.kicad_sch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]
2024-04-12 Modified Schematic
    電解コンデンサの容量を10μFから47μFに変更
    電池ソケットのシルク印刷の切り欠き位置が間違っていたのを修正
    不要なファイルの削除
    その他細かな修正
    Changed the capacitance of electrolytic capacitor from 10uF to 47uF.
    Fixed an issue where the notch position on the silkscreen print on the battery socket was incorrect.
    Delete unnecessary files.
    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
    [ESE2RAM-Cartridge-74670.csv, ESE2RAM-Cartridge-74670.kicad_pcb, ESE2RAM-Cartridge-74670.kicad_sch]
2024-04-12 Modified README
    READMEの部品表を回路図に合わせて修正
    その他細かな文言の修正
    Modified the README parts list to match the schematic.
    Other minor wording corrections.
2024-04-13 Modified Schematic
    部品の配置およびフットプリントの修正と、ガーバーデータへの反映
    Modify part placement and footprint and reflect in Gerber data.
    [ESE2RAM-Cartridge-74670.csv, ESE2RAM-Cartridge-74670.kicad_pcb, ESE2RAM-Cartridge-74670.kicad_sch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]
2024-04-13 Modified README
    修正した回路図に合わせて組み立て方を修正
    Modified "How to assemble" according to the revised schematic.
2024-04-13 Modified Schematic
    カードエッジコネクタのパッド形状(SW2/+12V/-12V)を修正
    Corrected the pad shape (SW2/+12V/-12V) of the card edge connector.
    [ESE2RAM-Cartridge-74670.kicad_pcb]
2024-04-14 Modified Schematic, and README
    電解コンデンサのフットプリントを修正
    組み立て方に電解コンデンサの実装方法を追記
    Fixed electrolytic capacitor footprint.
    Added the mounting method of electrolytic capacitor to "How to assemble".
    [ESE2RAM-Cartridge-74670.kicad_pcb]
2024-06-08 Updated Schematic & Gerber data.
    Updated to revision 4.
    [ESE2RAM-Cartridge-74670.kicad_pcb, ESE2RAM-Cartridge-74670.kicad_sch, bom.csv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]
2024-07-23 Modified README
    「使い方(メガROMソフトウェアを動かす場合)」の項目にセグメント(バンク番号)の初期化について記載
    Initialization of segments (bank numbers) is described in the "How to use (when running Mega ROM software)" section.
2024-10-08 Modified README
    Corrected wording in README
    READMEの文言ほか修正
2024-10-08 Modified Pictures
    基板写真のリンクと画像データを修正
    Corrected the board photo link and image data.
2024-10-08 Updated Schematic & Gerber data
    回路図データとガーバーデータを更新
    Updated Schematic & Gerber data.
    [ESE2RAM-Cartridge-74670.kicad_pcb, ESE2RAM-Cartridge-74670.kicad_sch]
2025-02-10 Add assemble_manual
    Add Japanese assemble manual
2025-02-10 Modified README
    バンク初期値の記述の修正。
    Correction of bank initial value description.
2025-03-11 Add Assembly manulal & ese2boot command
    日本語版組み立てマニュアルを追加
    Added Japanese assembly manual
    バンク初期化を行いブートする補助コマンドESE2BOOT.COMを追加
    Added auxiliary command ESE2BOOT.COM to initialize banks and boot.
2025-03-11 Assembly Manual & README modified
    組み立てマニュアルの画像挿し替えと細かな文言の修正
    The images in the assembly manual have been replaced and minor wording has been corrected.
    READMEの「使い方」の項目に初期化コードの例を追加
    Added example initialization code to the "How to use" section of the README.
2025-03-12 Update README.md
    セグメント番号初期値の表を修正
    Corrected the table of segment number initial values.
2025-03-23 PCB modified
    PCBを修正
    PCB modified.
    U4, U5, IC1の位置を下にずらした
    U4, U5, and IC1 shifted downward.
    Other minor modifications.
    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
    [ESE2RAM-Cartridge-74670.kicad_pcb, ESE2RAM-Cartridge-74670.kicad_sch, positions.csv]
2025-04-06 Modified Schematic
    一部MSX機種での動作不良修正のため74HC00/74HC32/74HC138を74AHCシリーズに変更
    Changed 74HC00/74HC32/74HC138 to 74AHC series to fix malfunction on some MSX models.
    [ESE2RAM-Cartridge-74670.kicad_pcb, ESE2RAM-Cartridge-74670.kicad_sch, bom.csv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]
2025-04-06 Modified README
    回路図に合わせてREADMEに記載の部品表を修正
    The parts list in the README has been updated to match the schematic.
2025-04-06 Modified PCB
    基板上のシルク印刷のバージョン番号を修正
    Corrected version number on PCB silkscreen.
    [ESE2RAM-Cartridge-74670.kicad_pcb]
2025-04-11 Modified ESE2BOOT.COM & Schematic
    ESE2BOOT.COMのバグ修正
    Fixed a bug in ESE2BOOT.COM
    回路図データの微修正
    Minor corrections to schematic data.
    [ESE2RAM-Cartridge-74670.kicad_pcb, ESE2RAM-Cartridge-74670.kicad_sch]
2025-04-12 Modified README
    READMEの部品表に部品変更の注意書きを足した
    Added a note about part changes to the README parts list.
2025-04-13 Modified schematic data
    一部のシンボルをプロジェクトのライブラリにコピーし、それに合わせ回路図を修正した
    I copied some symbols into the project library and modified the schematic accordingly.
    [ESE2RAM-Cartridge-74670.kicad_pcb, ESE2RAM-Cartridge-74670.kicad_sch]
2025-04-20 Modified README and assemble_manual
    READMEに互換性情報の項目を追加
    Added compatibility information section to README.
    assemble_manualにRAM容量減量の改造例を追加
    Added an example of a modification to reduce RAM capacity to the assemble_manual.
    その他の微細な修正
    Other minor fixes.
